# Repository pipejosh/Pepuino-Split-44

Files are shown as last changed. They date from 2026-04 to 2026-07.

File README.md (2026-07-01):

### Pepuino Split 44

This is a custom wireless keyboard inpired in the corne and sofle layout so my wrists arent crippled anymore!
A 44 keys keybaord wireless powered by a super mini (the cheapest BT microcontroller I could find) its wirelessssssss btw!
Featuring really cool art and bluetooth connectivity!

### Images

## IRL BUILD!

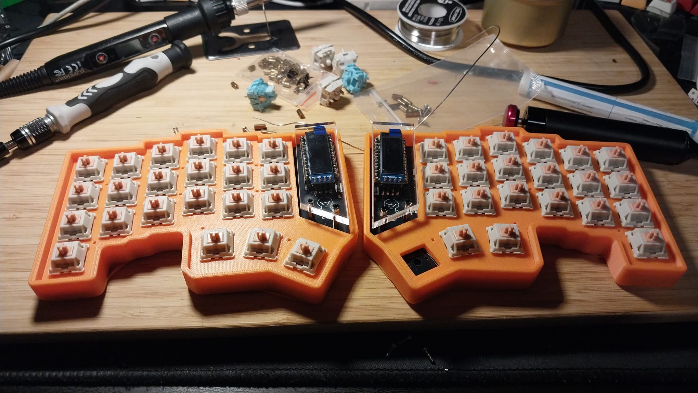
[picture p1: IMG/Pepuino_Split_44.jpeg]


## Render

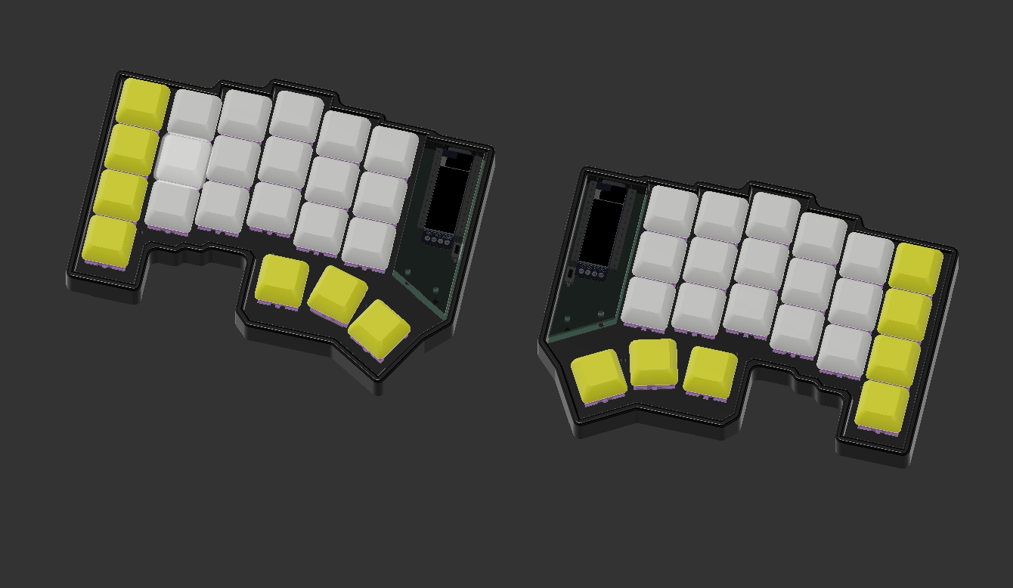
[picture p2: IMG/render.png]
Render


## Case

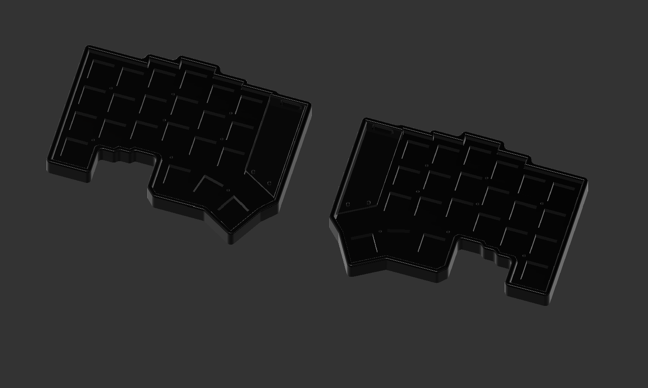
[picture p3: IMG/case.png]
Case


## PCB

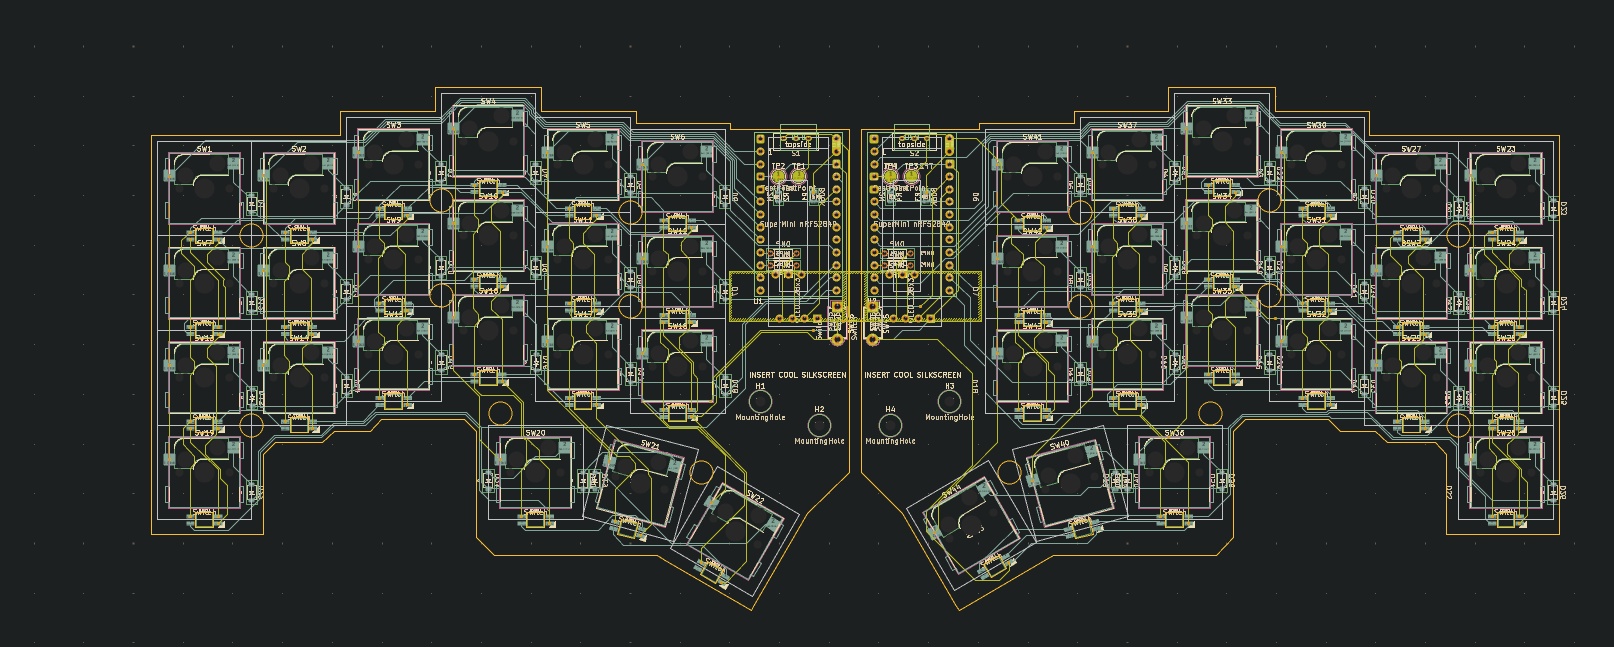
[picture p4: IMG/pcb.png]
Pcb


## Schematic

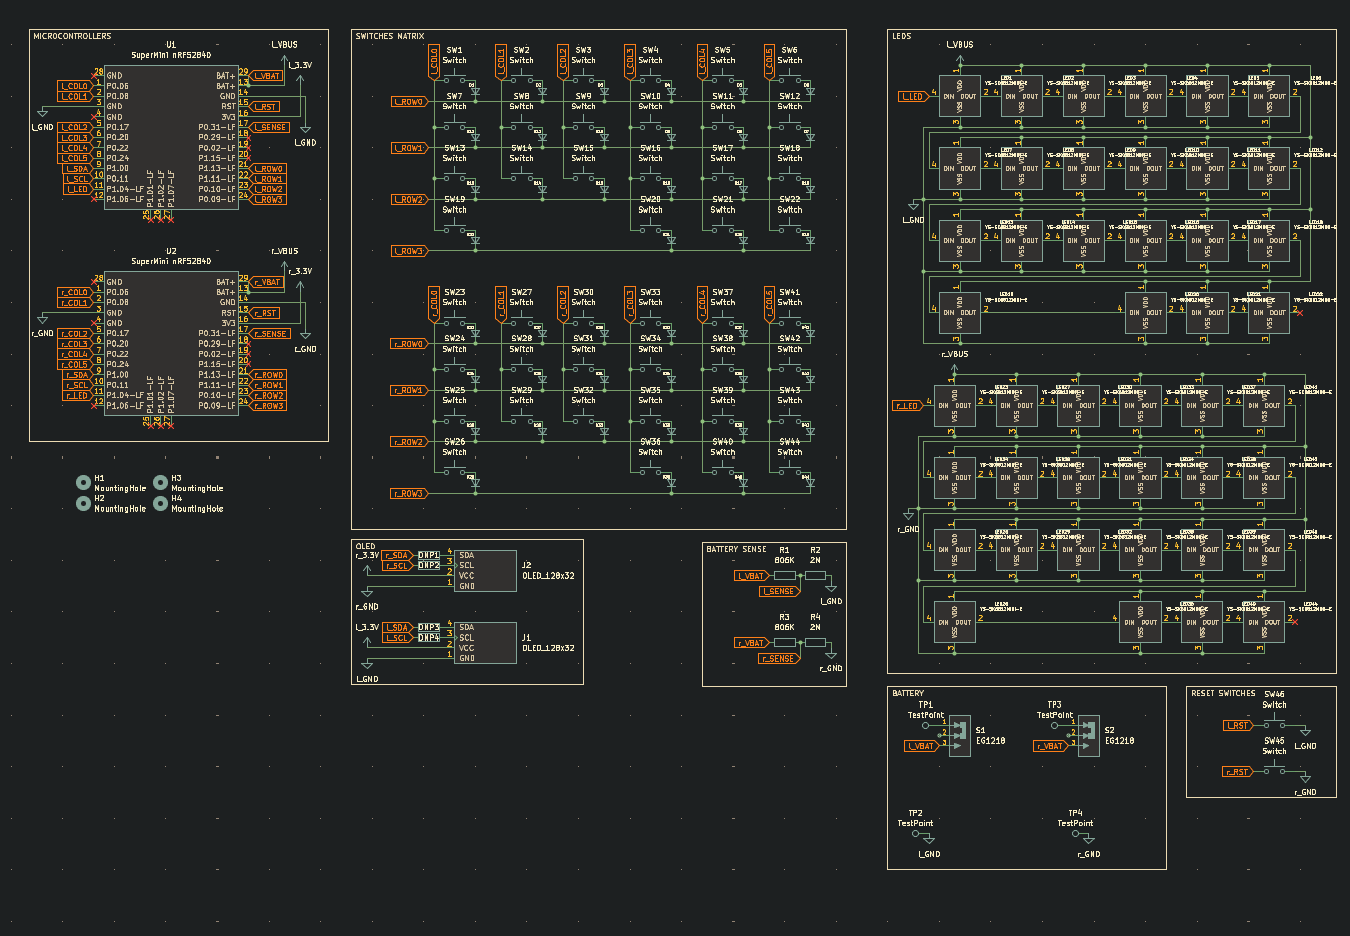
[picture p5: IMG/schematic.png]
Schematic


## BOM

### Components List

| Name | Purpose | Quantity | Total Cost (USD) | Distributor | Link |
| :--- | :--- | :---: | :---: | :--- | :--- |
| **m2 5mm standoff** | Assembly | 50 | $2.21 | AliExpress | [Link](https://www.aliexpress.com/item/32975966103.html) |
| **m2 2mm screw** | Assembly | 50 | $1.79 | AliExpress | [Link](https://www.aliexpress.com/item/1005005070119421.html) |
| **THT 4.7K resistor** | Pull-up resistor | 20 | $1.77 | AliExpress | [Link](https://www.aliexpress.com/item/1005006704431738.html) |
| **0805 2M Resistor** | Voltage divider | 100 | $1.55 | AliExpress | [Link](https://www.aliexpress.com/item/1005004145810949.html) |
| **0805 820K Resistor** | Voltage divider | 100 | $1.79 | AliExpress | [Link](https://www.aliexpress.com/item/1005004145810949.html) |
| **Battery 3.7V 110mAh** | Keyboard power | 2 | $8.87 | AliExpress | [Link](https://www.google.com/search?q=https://www.aliexpress.com/item/1005011794722407.html) |
| **MSK-12D19** | Slide switch | 20 | $2.05 | AliExpress | [Link](https://www.aliexpress.com/item/1005009651088272.html) |
| **Switches** | Bao Bao Dragon | 45 | $10.95 | AliExpress | [Link](https://www.aliexpress.com/item/1005012005250603.html) |
| **Reset Button** | Reset button | 10 | $2.70 | AliExpress | [Link](https://www.aliexpress.com/item/1005009739698023.html) |
| **SK6812 MINI-E RGB** | RGB Lighting | 50 | $3.86 | AliExpress | [Link](https://www.google.com/search?q=https://www.aliexpress.com/item/1005005193716172.html) |
| **1N4148W T4 SOD-123** | Diodes | 100 | $3.18 | AliExpress | [Link](https://www.aliexpress.com/item/1005007160563285.html) |
| **Hotswap sockets** | Easy replace switches | 50 | $10.13 | AliExpress | [Link](https://www.google.com/search?q=https://www.aliexpress.com/item/1005009254258549.html) |
| **OLED 0.91"** | Display | 2 | $5.52 | AliExpress | [Link](https://www.google.com/search?q=https://www.aliexpress.com/item/1005011783382489.html) |
| **Super mini NRF52840** | Microcontroller | 2 | $5.30 | AliExpress | [Link](https://www.aliexpress.com/item/1005007078900079.html) |
| **Components Subtotal** | | | $61.67 | | |

-----

### PCB Manufacturing

| Name | Purpose | Quantity | Manufacturing | Shipping | Total Cost (USD) | Distributor |
| :--- | :--- | :---: | :---: | :---: | :---: | :--- |
| **PCB** | The main circuit board | 5 | $20.00 | $13.26 | $33.26 | JLCPCB |

-----

**Grand Total Project Estimate Cost: $94.93**

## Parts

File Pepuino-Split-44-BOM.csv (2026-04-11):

Name | Purpose | Quantity | Total Cost (USD) | Link | Distributor
m2 5mm standoff | asseemblyy | 50 | 2.21 | https://www.aliexpress.com/item/32975966103.html | aliexpress
m2 2mm screw | assembly | 50 | 1.79 | https://www.aliexpress.com/item/1005005070119421.html | aliexpress
THT 4.7K resistor | pull up resistor | 20 | 1.77 | https://www.aliexpress.com/item/1005006704431738.html | aliexpress
0805 2M Resistor | Voltagee dividor | 100 | 1.55 | https://www.aliexpress.com/item/1005004145810949.html | aliexpress
0805 820K Resistor | Votage dividor | 100 | 1.79 | https://www.aliexpress.com/item/1005004145810949.html | aliexpress
PCB | the pcb | 5 | 20.00 | https://jlcpcb.com/ | JLCPCB
Battery 3.7 110mah | the battery of the keyboard | 2 | 8.87 | https://www.aliexpress.com/item/1005011794722407.html | aliexpress
MSK-12D19 | Slide switch | 20 | 2.05 | https://www.aliexpress.com/item/1005009651088272.html | aliexpress
Switches | Bao Bao Dragon | 45 | 10.95 | https://www.aliexpress.com/item/1005012005250603.html | aliepxress
Reset Button | Reset button | 10 | 2.70 | https://www.aliexpress.com/item/1005009739698023.html | aliexpress
SK6812 MINI-E RGB | RGBBBBBB | 50 | 3.86 | https://www.aliexpress.com/item/1005005193716172.html | aliexpress
1N4148W T4 SOD-123 | Diodes | 100 | 3.18 | https://www.aliexpress.com/item/1005007160563285.html | aliexpress
Hotswap sockets | Easy reaple switches | 50 | 10.13 | https://www.aliexpress.com/item/1005009254258549.html | aliexpress
Oled 0.91" | Oled display | 2 | 5.52 | https://www.aliexpress.com/item/1005011783382489.html | aliexpress
Super mini NRF52840 | The microcontroller | 2 | 5.30 | https://www.aliexpress.com/item/1005007078900079.html | aliexpress

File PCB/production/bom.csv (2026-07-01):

Designator | Footprint | Quantity | Value | LCSC Part #
D1, D10, D11, D12, D13, D14, D15, D16, D17, D18, D19, D2, D20, D21, D22, D23, D24, D25, D26, D27, D28, D29, D3, D30, D31, D32, D33, D34, D35, D36, D37, D38, D39, D4, D40, D41, D42, D43, D44, D5, D6, D7, D8, D9 | Diode_SOD-123 | 44 | ~
J1, J2 | OLED_128x32 | 2 | OLED_128x32
LED1, LED10, LED11, LED12, LED13, LED14, LED15, LED16, LED17, LED18, LED19, LED2, LED20, LED21, LED22, LED23, LED24, LED25, LED26, LED27, LED28, LED29, LED3, LED30, LED31, LED32, LED33, LED34, LED35, LED36, LED37, LED38, LED39, LED4, LED40, LED41, LED42, LED43, LED44, LED5, LED6, LED7, LED8, LED9 | YS-SK6812MINI-E | 44 | YS-SK6812MINI-E
R1, R3 | 0805 | 2 | 806K
R2, R4 | 0805 | 2 | 2M
S1, S2 | TGSW_MSK-12D19 | 2 | EG1218
SW1, SW10, SW11, SW12, SW13, SW14, SW15, SW16, SW17, SW18, SW19, SW2, SW20, SW21, SW22, SW23, SW24, SW25, SW26, SW27, SW28, SW29, SW3, SW30, SW31, SW32, SW33, SW34, SW35, SW36, SW37, SW38, SW39, SW4, SW40, SW41, SW42, SW43, SW44, SW5, SW6, SW7, SW8, SW9 | Hotswap_MX_1.00u | 44 | Switch
SW45, SW46 | Button_MJTP1243 | 2 | Switch
TP1, TP2, TP3, TP4 | TestPoint_Pad_D2.5mm | 4 | TestPoint

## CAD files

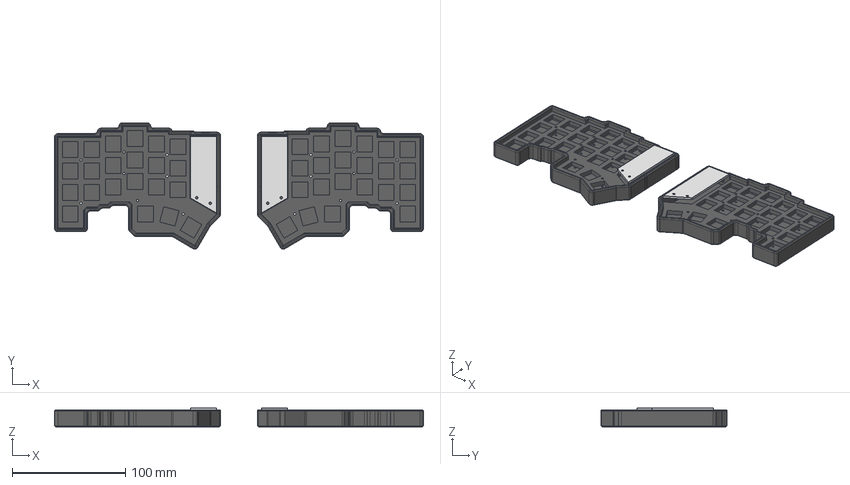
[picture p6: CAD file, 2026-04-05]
CAD/pepuinoSplit44Case.step
326.5 x 111.8 x 16.6 mm

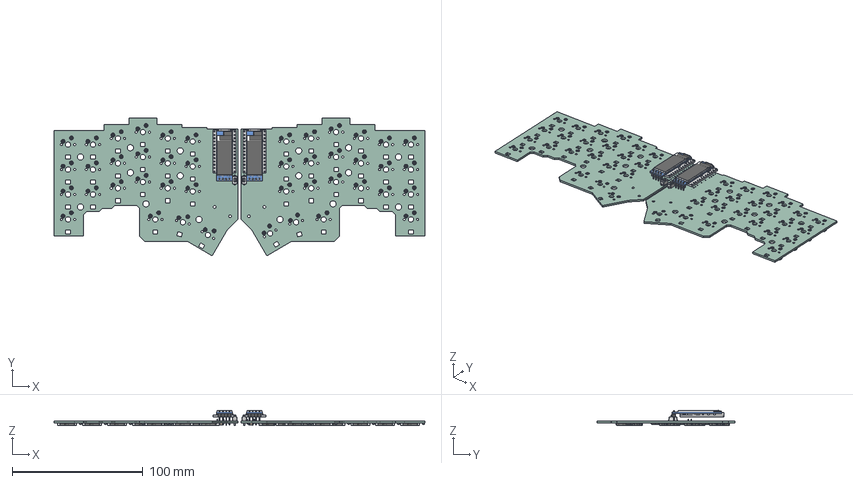
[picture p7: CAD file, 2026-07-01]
PCB/pepuinoSplit44finalfinal.step
283.4 x 105.2 x 11.8 mm
Hotswap_MX x 44
promicronrf52840 x 2
SW_PUSH_6mm_H4.3mm.step x 2
OLED_0.91_128x32 x 2
Pin Header 4 x 1 TH 2.54mm Pitch x 2
RESC-0603 x 26
2SD0601A x 2
Diode_SOD-123 x 44
R_Axial_DIN0204_L3.6mm_D1.6mm_P5.08mm_Horizontal x 4
R_0805_2012Metric x 4
pepuinoSplit48_PCB_1
pepuinoSplit48_PCB_2

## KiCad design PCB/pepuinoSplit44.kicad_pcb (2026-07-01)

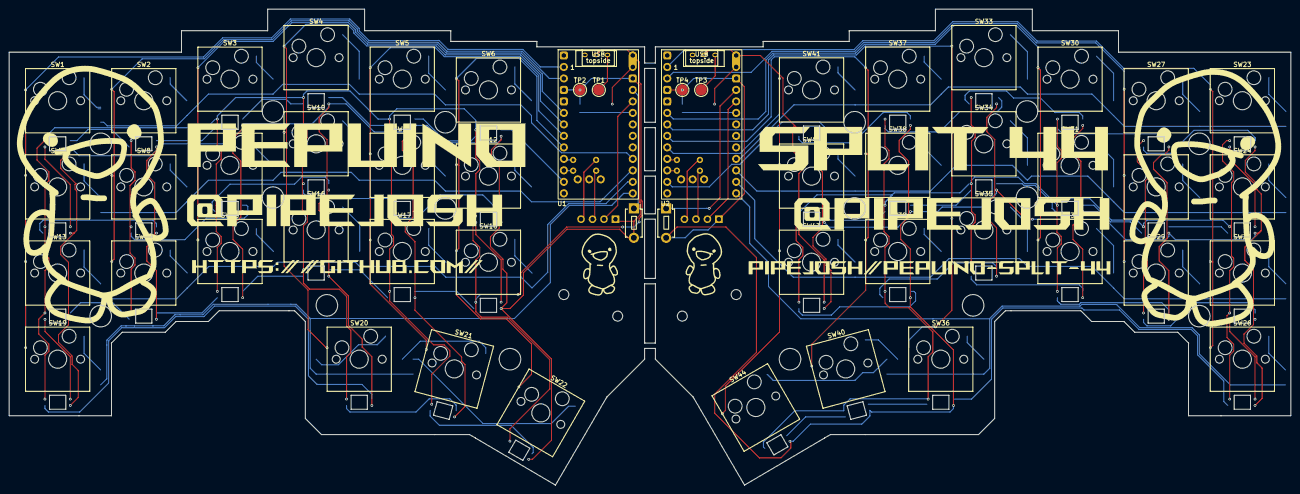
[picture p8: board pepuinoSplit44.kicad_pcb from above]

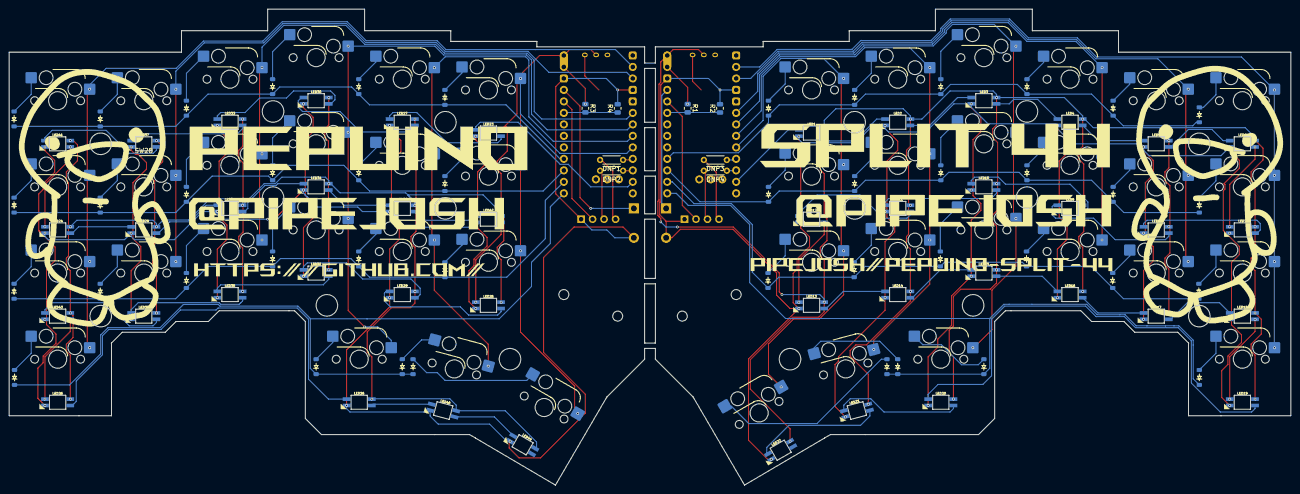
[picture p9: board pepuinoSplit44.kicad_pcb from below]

Board: 2 copper layers, 283.4 x 105.2 mm, 156 parts (96 on the bottom side), 128 nets.

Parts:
D1, D2, D3, D4, D5, D6, D7, D8, D9, D10, D11, D12, D13, D14, D15, D16, D17, D18, D19, D20, D21, D22, D23, D24, D25, D26, D27, D28, D29, D30, D31, D32, D33, D34, D35, D36, D37, D38, D39, D40, D41, D42, D43, D44: Diode_SOD-123
DNP1, DNP2, DNP3, DNP4: DNP; R_Axial_DIN0204_L3.6mm_D1.6mm_P5.08mm_Horizontal
H1, H2, H3, H4: MountingHole; MountingHole_2.2mm_M2
J1, J2: OLED_128x32
LED1, LED2, LED3, LED4, LED5, LED6, LED7, LED8, LED9, LED10, LED11, LED12, LED13, LED14, LED15, LED16, LED17, LED18, LED19, LED20, LED21, LED22, LED23, LED24, LED25, LED26, LED27, LED28, LED29, LED30, LED31, LED32, LED33, LED34, LED35, LED36, LED37, LED38, LED39, LED40, LED41, LED42, LED43, LED44: YS-SK6812MINI-E
R1, R3: 806K; R_0805_2012Metric
R2, R4: 2M; R_0805_2012Metric
S1, S2: EG1218; TGSW_MSK-12D19
SW1, SW2, SW3, SW4, SW5, SW6, SW7, SW8, SW9, SW10, SW11, SW12, SW13, SW14, SW15, SW16, SW17, SW18, SW19, SW20, SW21, SW22, SW23, SW24, SW25, SW26, SW27, SW28, SW29, SW30, SW31, SW32, SW33, SW34, SW35, SW36, SW37, SW38, SW39, SW40, SW41, SW42, SW43, SW44: Switch; Hotswap_MX_1.00u
SW45, SW46: Switch; Button_MJTP1243
TP1, TP2, TP3, TP4: TestPoint; TestPoint_Pad_D2.5mm
U1, U2: SuperMini nRF52840; SuperMini_nRF52840_AH_USBup

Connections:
unnamed: D1.2 (A), SW1.2
unnamed: D2.2 (A), SW2.2
unnamed: D3.2 (A), SW3.2
unnamed: D4.2 (A), SW4.2
unnamed: D5.2 (A), SW5.2
unnamed: D6.2 (A), SW6.2
unnamed: D7.2 (A), SW12.2
unnamed: D8.2 (A), SW11.2
unnamed: D9.2 (A), SW10.2
unnamed: D10.2 (A), SW9.2
unnamed: D11.2 (A), SW8.2
unnamed: D12.2 (A), SW7.2
unnamed: D13.2 (A), SW13.2
unnamed: D14.2 (A), SW14.2
unnamed: D15.2 (A), SW15.2
unnamed: D16.2 (A), SW16.2
unnamed: D17.2 (A), SW17.2
unnamed: D18.2 (A), SW18.2
unnamed: D19.2 (A), SW22.2
unnamed: D20.2 (A), SW21.2
unnamed: D21.2 (A), SW20.2
unnamed: D22.2 (A), SW19.2
unnamed: D23.2 (A), SW23.2
unnamed: D24.2 (A), SW24.2
unnamed: D25.2 (A), SW25.2
unnamed: D26.2 (A), SW26.2
unnamed: D27.2 (A), SW27.2
unnamed: D28.2 (A), SW28.2
unnamed: D29.2 (A), SW29.2
unnamed: D30.2 (A), SW30.2
unnamed: D31.2 (A), SW31.2
unnamed: D32.2 (A), SW32.2
unnamed: D33.2 (A), SW33.2
unnamed: D34.2 (A), SW34.2
unnamed: D35.2 (A), SW35.2
unnamed: D36.2 (A), SW36.2
unnamed: D37.2 (A), SW37.2
unnamed: D38.2 (A), SW38.2
unnamed: D39.2 (A), SW39.2
unnamed: D40.2 (A), SW40.2
unnamed: D41.2 (A), SW41.2
unnamed: D42.2 (A), SW42.2
unnamed: D43.2 (A), SW43.2
unnamed: D44.2 (A), SW44.2
unnamed: DNP4.2, J1.3 (SCL)
unnamed: DNP3.2, J1.4 (SDA)
unnamed: DNP2.2, J2.3 (SCL)
unnamed: DNP1.2, J2.4 (SDA)
unnamed: LED1.2 (DOUT), LED2.4 (DIN)
unnamed: LED2.2 (DOUT), LED3.4 (DIN)
unnamed: LED3.2 (DOUT), LED4.4 (DIN)
unnamed: LED4.2 (DOUT), LED5.4 (DIN)
unnamed: LED5.2 (DOUT), LED6.4 (DIN)
unnamed: LED6.2 (DOUT), LED7.4 (DIN)
unnamed: LED7.2 (DOUT), LED8.4 (DIN)
unnamed: LED8.2 (DOUT), LED9.4 (DIN)
unnamed: LED9.2 (DOUT), LED10.4 (DIN)
unnamed: LED10.2 (DOUT), LED11.4 (DIN)
unnamed: LED11.2 (DOUT), LED12.4 (DIN)
unnamed: LED12.2 (DOUT), LED13.4 (DIN)
unnamed: LED13.2 (DOUT), LED14.4 (DIN)
unnamed: LED14.2 (DOUT), LED15.4 (DIN)
unnamed: LED15.2 (DOUT), LED16.4 (DIN)
unnamed: LED16.2 (DOUT), LED17.4 (DIN)
unnamed: LED17.2 (DOUT), LED18.4 (DIN)
unnamed: LED18.2 (DOUT), LED19.4 (DIN)
unnamed: LED19.2 (DOUT), LED20.4 (DIN)
unnamed: LED20.2 (DOUT), LED21.4 (DIN)
unnamed: LED21.2 (DOUT), LED22.4 (DIN)
unnamed: LED23.2 (DOUT), LED27.4 (DIN)
unnamed: LED24.4 (DIN), LED41.2 (DOUT)
unnamed: LED24.2 (DOUT), LED28.4 (DIN)
unnamed: LED25.4 (DIN), LED42.2 (DOUT)
unnamed: LED25.2 (DOUT), LED29.4 (DIN)
unnamed: LED26.4 (DIN), LED43.2 (DOUT)
unnamed: LED26.2 (DOUT), LED36.4 (DIN)
unnamed: LED27.2 (DOUT), LED30.4 (DIN)
unnamed: LED28.2 (DOUT), LED31.4 (DIN)
unnamed: LED29.2 (DOUT), LED32.4 (DIN)
unnamed: LED30.2 (DOUT), LED33.4 (DIN)
unnamed: LED31.2 (DOUT), LED34.4 (DIN)
unnamed: LED32.2 (DOUT), LED35.4 (DIN)
unnamed: LED33.2 (DOUT), LED37.4 (DIN)
unnamed: LED34.2 (DOUT), LED38.4 (DIN)
unnamed: LED35.2 (DOUT), LED39.4 (DIN)
unnamed: LED36.2 (DOUT), LED40.4 (DIN)
unnamed: LED37.2 (DOUT), LED41.4 (DIN)
unnamed: LED38.2 (DOUT), LED42.4 (DIN)
unnamed: LED39.2 (DOUT), LED43.4 (DIN)
unnamed: LED40.2 (DOUT), LED44.4 (DIN)
unnamed: S1.1, TP1.1 (1_1)
unnamed: S2.1, TP3.1 (1_1)
l_3.3V: J1.2 (VCC), U1.16 (3V3)
l_COL0: SW1.1, SW7.1, SW13.1, SW19.1, U1.1 (P0.06)
l_COL1: SW2.1, SW8.1, SW14.1, U1.2 (P0.08)
l_COL2: SW3.1, SW9.1, SW15.1, U1.5 (P0.17)
l_COL3: SW4.1, SW10.1, SW16.1, SW20.1, U1.6 (P0.20)
l_COL4: SW5.1, SW11.1, SW17.1, SW21.1, U1.7 (P0.22)
l_COL5: SW6.1, SW12.1, SW18.1, SW22.1, U1.8 (P0.24)
l_GND: J1.1 (GND), LED1.3 (VSS), LED2.3 (VSS), LED3.3 (VSS), LED4.3 (VSS), LED5.3 (VSS), LED6.3 (VSS), LED7.3 (VSS), LED8.3 (VSS), LED9.3 (VSS), LED10.3 (VSS), LED11.3 (VSS), LED12.3 (VSS), LED13.3 (VSS), LED14.3 (VSS), LED15.3 (VSS), LED16.3 (VSS), LED17.3 (VSS), LED18.3 (VSS), LED19.3 (VSS), LED20.3 (VSS), LED21.3 (VSS), LED22.3 (VSS), R2.2, SW46.2, TP2.1 (1_1), U1.3 (GND), U1.14 (GND)
l_LED: LED1.4 (DIN), U1.11 (P1.04-LF)
l_ROW0: D1.1 (K), D2.1 (K), D3.1 (K), D4.1 (K), D5.1 (K), D6.1 (K), U1.21 (P1.13-LF)
l_ROW1: D7.1 (K), D8.1 (K), D9.1 (K), D10.1 (K), D11.1 (K), D12.1 (K), U1.22 (P1.11-LF)
l_ROW2: D13.1 (K), D14.1 (K), D15.1 (K), D16.1 (K), D17.1 (K), D18.1 (K), U1.23 (P0.10-LF)
l_ROW3: D19.1 (K), D20.1 (K), D21.1 (K), D22.1 (K), U1.24 (P0.09-LF)
l_RST: SW46.1, U1.15 (RST)
l_SCL: DNP4.1, U1.10 (P0.11)
l_SDA: DNP3.1, U1.9 (P1.00)
l_SENSE: R1.2, R2.1, U1.17 (P0.31-LF)
l_VBAT: LED1.1 (VDD), LED2.1 (VDD), LED3.1 (VDD), LED4.1 (VDD), LED5.1 (VDD), LED6.1 (VDD), LED7.1 (VDD), LED8.1 (VDD), LED9.1 (VDD), LED10.1 (VDD), LED11.1 (VDD), LED12.1 (VDD), LED13.1 (VDD), LED14.1 (VDD), LED15.1 (VDD), LED16.1 (VDD), LED17.1 (VDD), LED18.1 (VDD), LED19.1 (VDD), LED20.1 (VDD), LED21.1 (VDD), LED22.1 (VDD), R1.1, S1.2, U1.13 (BAT+), U1.29 (BAT+)
r_3.3V: J2.2 (VCC), U2.16 (3V3)
r_COL0: SW23.1, SW24.1, SW25.1, SW26.1, U2.1 (P0.06)
r_COL1: SW27.1, SW28.1, SW29.1, U2.2 (P0.08)
r_COL2: SW30.1, SW31.1, SW32.1, U2.5 (P0.17)
r_COL3: SW33.1, SW34.1, SW35.1, SW36.1, U2.6 (P0.20)
r_COL4: SW37.1, SW38.1, SW39.1, SW40.1, U2.7 (P0.22)
r_COL5: SW41.1, SW42.1, SW43.1, SW44.1, U2.8 (P0.24)
r_GND: J2.1 (GND), LED23.3 (VSS), LED24.3 (VSS), LED25.3 (VSS), LED26.3 (VSS), LED27.3 (VSS), LED28.3 (VSS), LED29.3 (VSS), LED30.3 (VSS), LED31.3 (VSS), LED32.3 (VSS), LED33.3 (VSS), LED34.3 (VSS), LED35.3 (VSS), LED36.3 (VSS), LED37.3 (VSS), LED38.3 (VSS), LED39.3 (VSS), LED40.3 (VSS), LED41.3 (VSS), LED42.3 (VSS), LED43.3 (VSS), LED44.3 (VSS), R4.2, SW45.2, TP4.1 (1_1), U2.3 (GND), U2.14 (GND)
r_LED: LED23.4 (DIN), U2.11 (P1.04-LF)
r_ROW0: D23.1 (K), D27.1 (K), D30.1 (K), D33.1 (K), D37.1 (K), D41.1 (K), U2.21 (P1.13-LF)
r_ROW1: D24.1 (K), D28.1 (K), D31.1 (K), D34.1 (K), D38.1 (K), D42.1 (K), U2.22 (P1.11-LF)
r_ROW2: D25.1 (K), D29.1 (K), D32.1 (K), D35.1 (K), D39.1 (K), D43.1 (K), U2.23 (P0.10-LF)
r_ROW3: D26.1 (K), D36.1 (K), D40.1 (K), D44.1 (K), U2.24 (P0.09-LF)
r_RST: SW45.1, U2.15 (RST)
r_SCL: DNP2.1, U2.10 (P0.11)
r_SDA: DNP1.1, U2.9 (P1.00)
r_SENSE: R3.2, R4.1, U2.17 (P0.31-LF)
r_VBAT: LED23.1 (VDD), LED24.1 (VDD), LED25.1 (VDD), LED26.1 (VDD), LED27.1 (VDD), LED28.1 (VDD), LED29.1 (VDD), LED30.1 (VDD), LED31.1 (VDD), LED32.1 (VDD), LED33.1 (VDD), LED34.1 (VDD), LED35.1 (VDD), LED36.1 (VDD), LED37.1 (VDD), LED38.1 (VDD), LED39.1 (VDD), LED40.1 (VDD), LED41.1 (VDD), LED42.1 (VDD), LED43.1 (VDD), LED44.1 (VDD), R3.1, S2.2, U2.13 (BAT+), U2.29 (BAT+)

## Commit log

2026-03-19 intintal commit
    [pepuinoSplit48.kicad_pcb, pepuinoSplit48.kicad_sch]
2026-04-05 create md + organize + update case
    [pepuinoSplit44Case.step]
2026-04-05 add BOM
    [Pepuino-Split-44-BOM.csv]
2026-04-11 Update readme + BOM + pcb + add firmware
    [Pepuino-Split-44-BOM.csv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]
2026-07-01 update the new version with the correct slider
    [bom.csv, designators.csv, pepuinoSplit44.kicad_pcb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]
